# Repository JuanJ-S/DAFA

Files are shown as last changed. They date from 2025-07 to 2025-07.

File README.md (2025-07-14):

# DAFA
Dispositivo de Análisis de Fugas de Agua
# Integrantes
 - Wilson David Cortes Gonzales
 - Juan Camilo Forero Castillo
 - Andres Felipe Martinez Roa
 - Fedor Santiago Palacios Hernandez
 - Juan José Santos Pineda
 - David Valero Garzon
# Descripción
Conjunto de sensores conectados a un microcontrolador central (ESP32), que monitorean el caudal y presión del agua en puntos especificos de un sistema de tuberias. El ESP32 se conecta mediante wifi a Blynk, en donde analizan los datos dados por los sensores y se determina si estan dentro de los limites establecidos. Si los valores estan por debajo de lo permitido, se interpreta una posible fuga o conexión no registrada en el sistema, lo cual hará que el dispositivo de una alerta.
# Palabras Clave
 - Perdida de Agua
 - Internet de las Cosas
 - Sensores 
 - ESP 32
 - Gestión Hídrica
 - Sostenibilidad
# Poster
Pendiente -> ¿Como que poster :c?
# Banner de Implementación del Proyecto
En proceso. Imagen preliminar
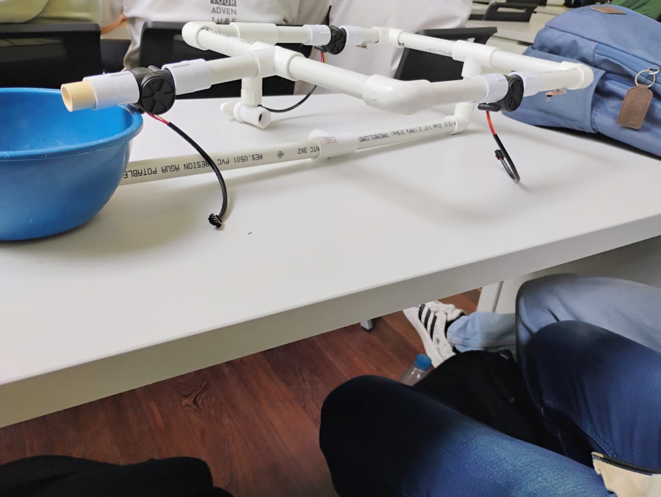
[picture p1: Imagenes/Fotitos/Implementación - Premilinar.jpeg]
Implementación Preliminar

# Video del Proyecto
Explicacion de: 
    - Problematica
    - Solución Planteada
    - Criterios para la toma de soluciones
    - Funcionamiento del proyecto para el usuario
    - Recomendaciones y Conclusiones

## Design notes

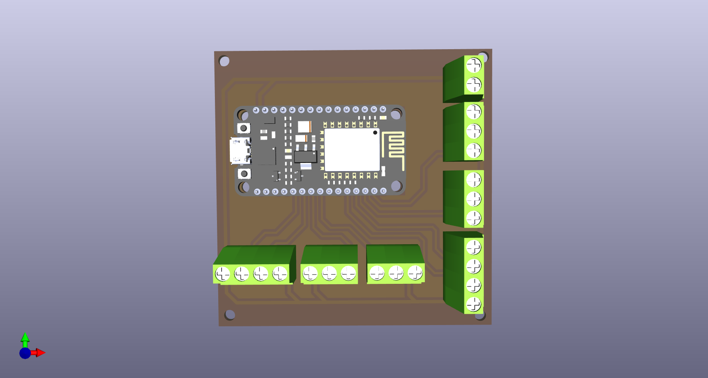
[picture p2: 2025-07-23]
Imagenes/Fotitos/Diseño 3D PCB.png

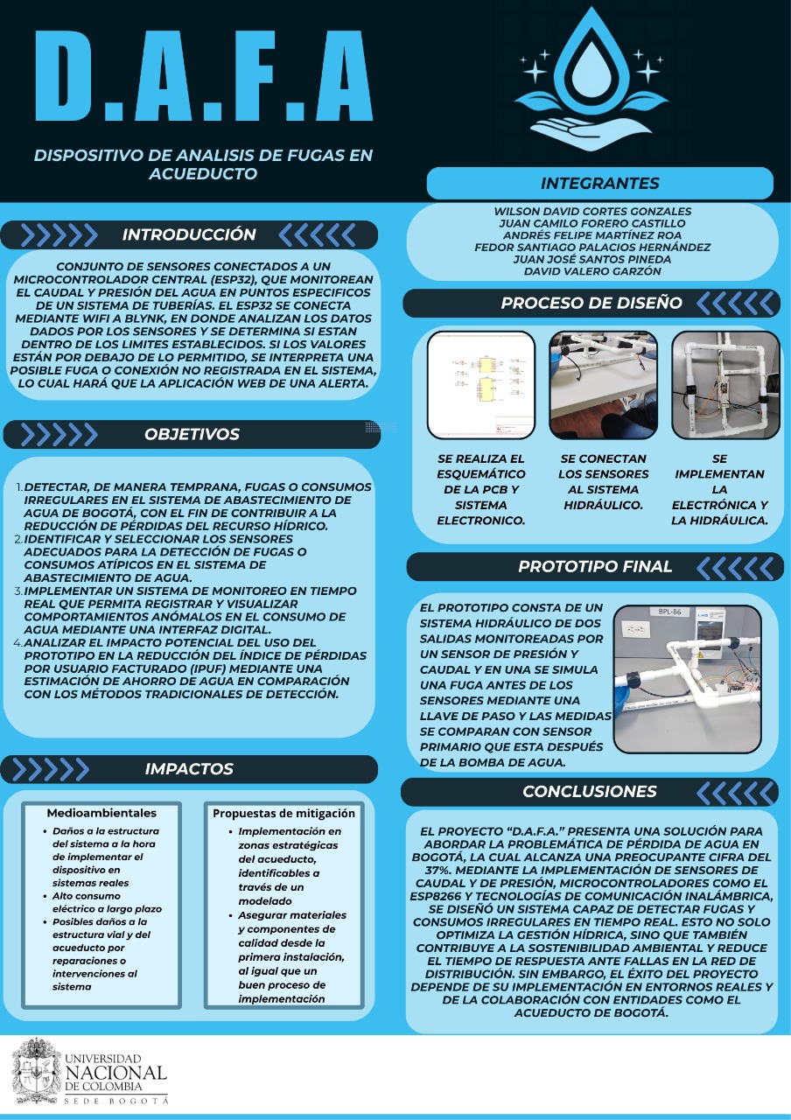
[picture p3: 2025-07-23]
Imagenes/Poster.jpeg

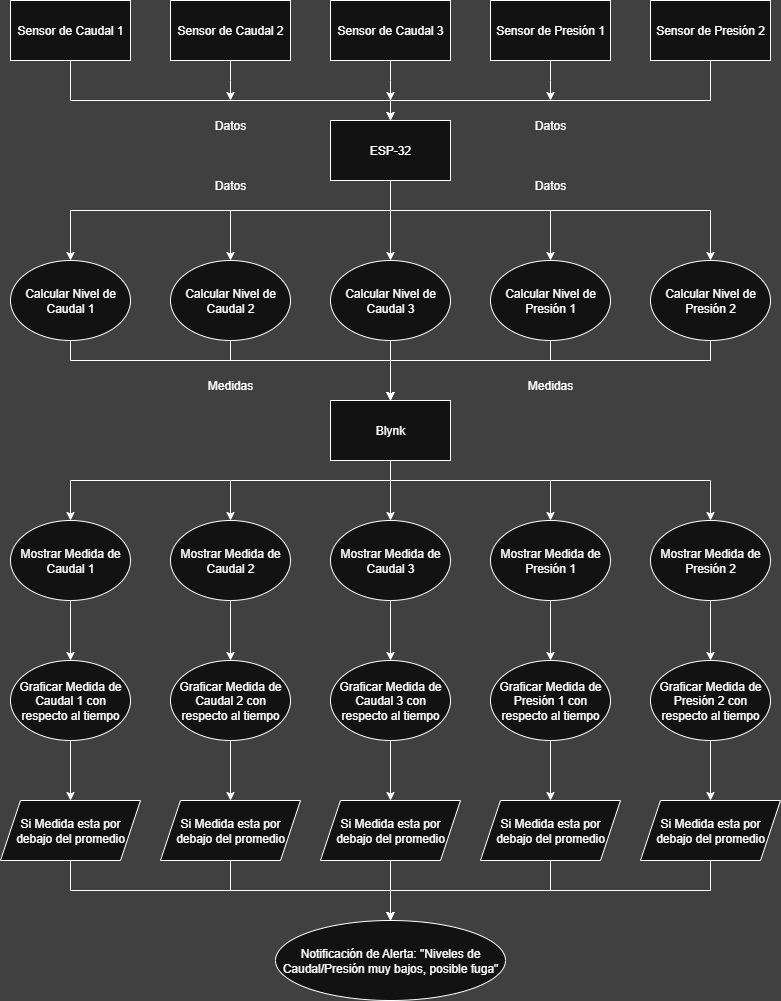
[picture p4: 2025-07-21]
Imagenes/Diagramas/Interacción con Blynk.drawio.png

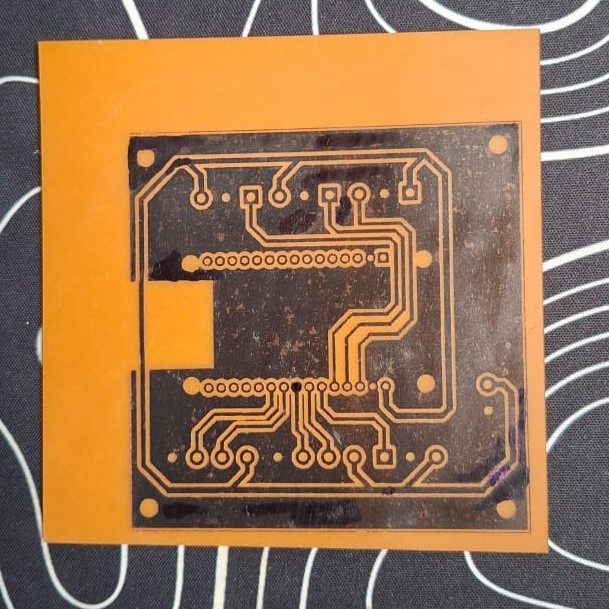
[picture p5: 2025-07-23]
Imagenes/Fotitos/Evidencias/PCB post-acido.jpeg

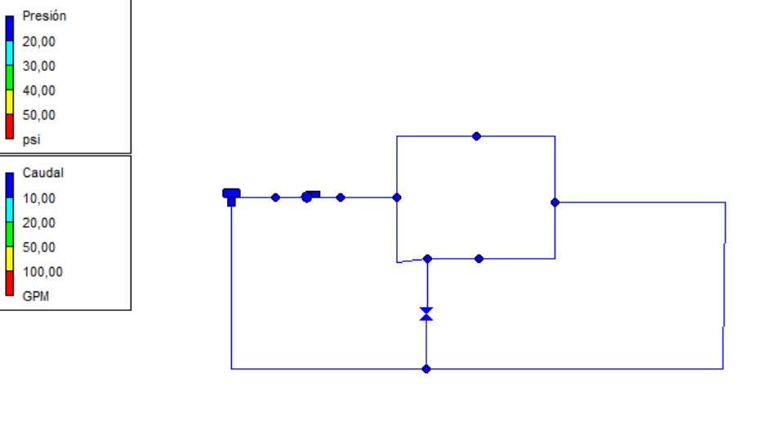
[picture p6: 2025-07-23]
Imagenes/Fotitos/Evidencias/Antigua Simulación.jpeg

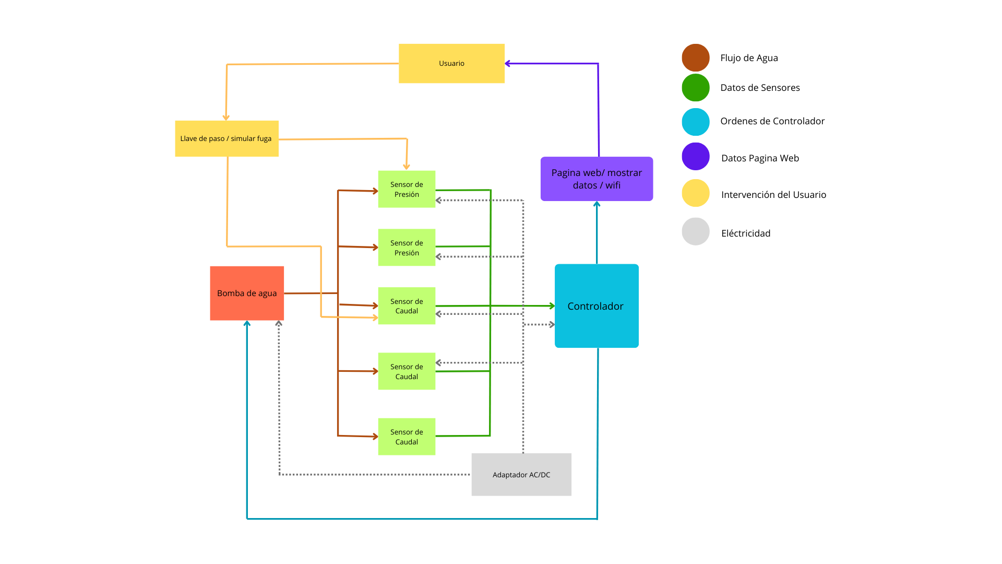
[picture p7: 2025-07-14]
Imagenes/Diagramas/Diagrama de Caja Negra.png

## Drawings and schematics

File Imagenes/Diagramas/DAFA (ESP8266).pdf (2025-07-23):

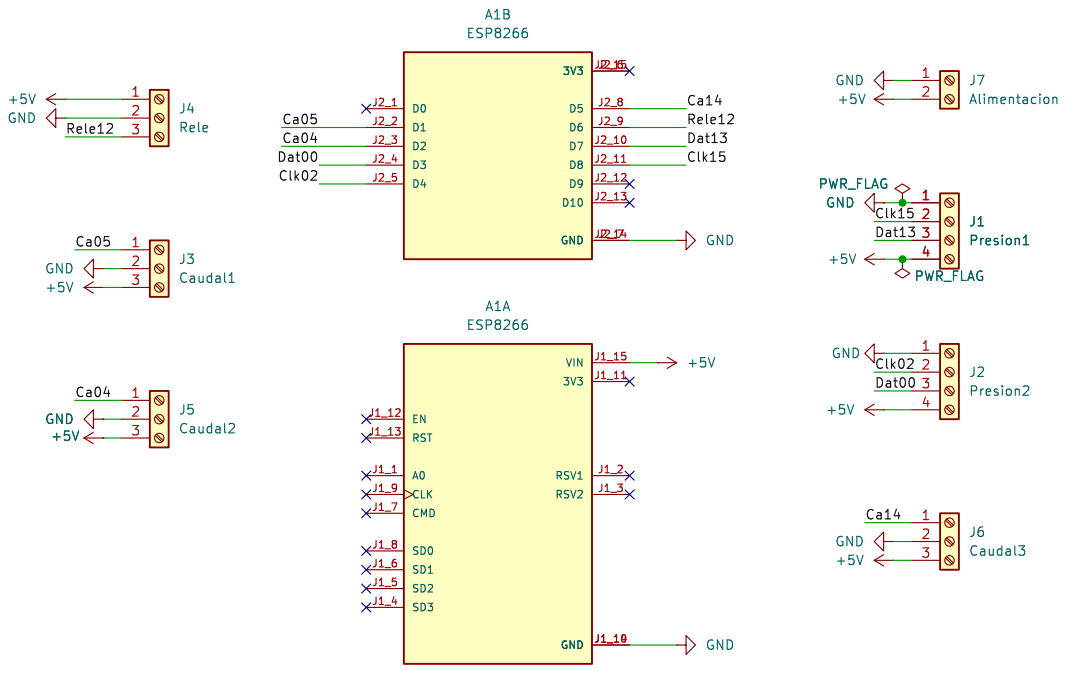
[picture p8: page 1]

Id: 1/1 Title: File: DAFA (ESP8266).kicad_sch Sheet: /

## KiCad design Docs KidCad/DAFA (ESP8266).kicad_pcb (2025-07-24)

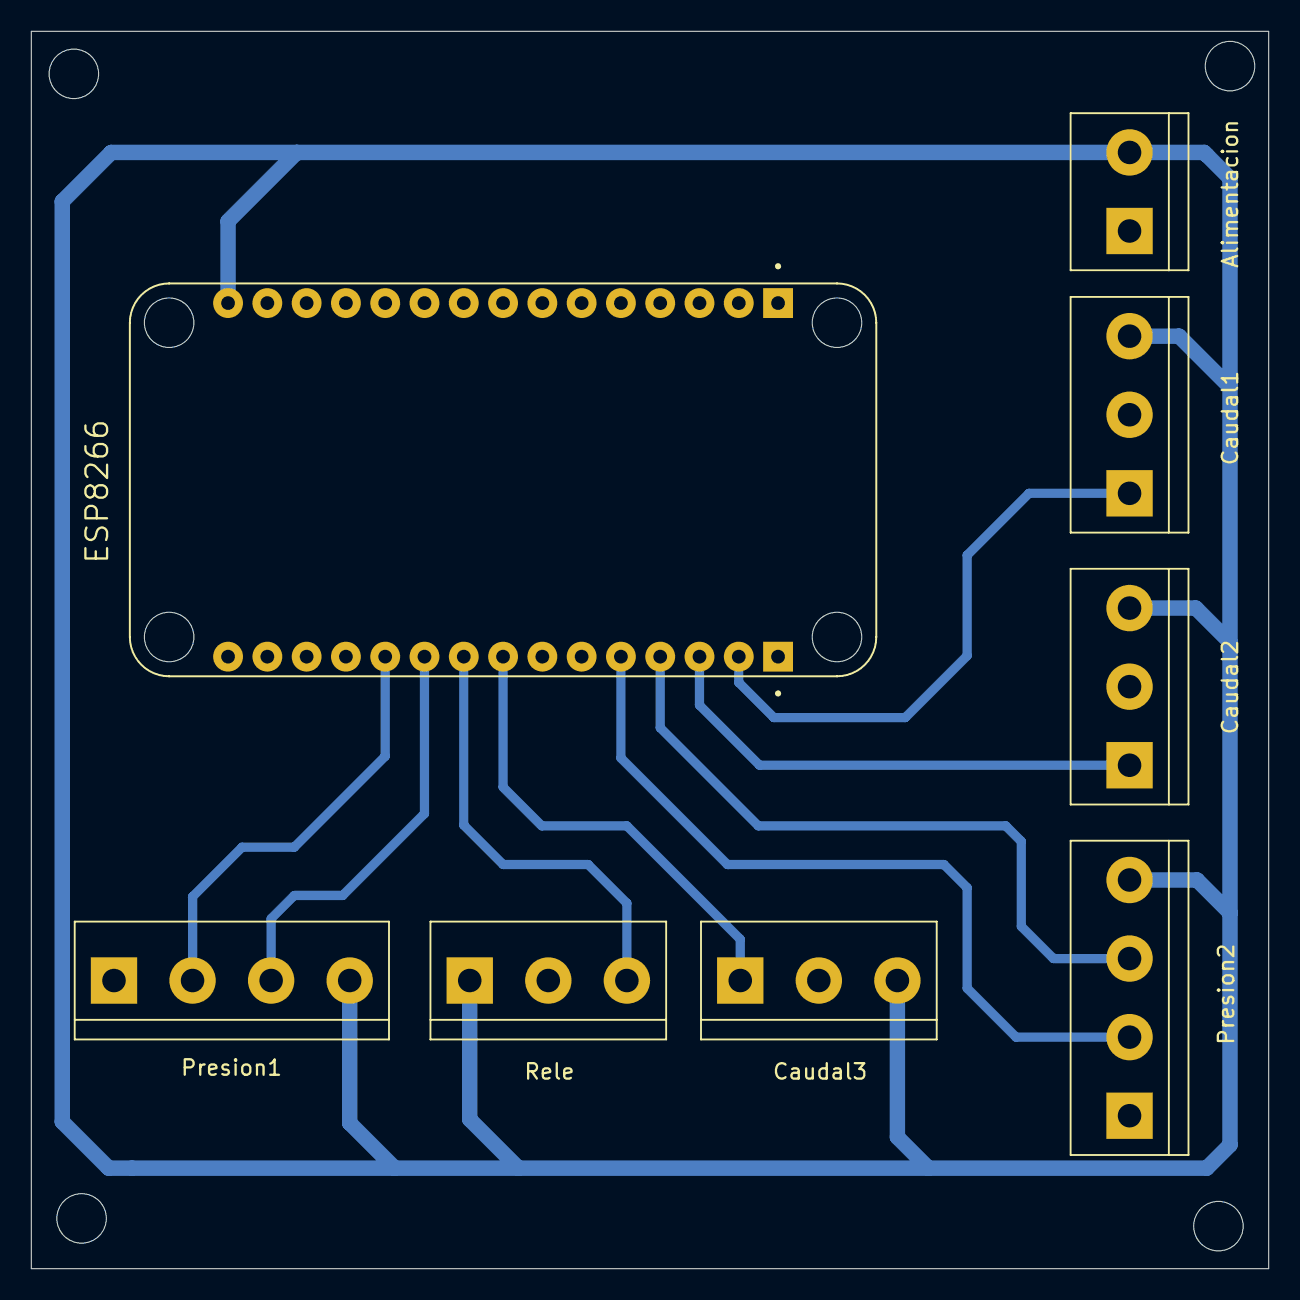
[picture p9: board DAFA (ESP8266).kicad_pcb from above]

Board: 2 copper layers, 80.0 x 80.0 mm, 8 parts (0 on the bottom side), 10 nets.

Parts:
Alimentacion: Alimentacion; TerminalBlock_bornier-2_P5.08mm
Caudal1: Caudal1; TerminalBlock_bornier-3_P5.08mm
Caudal2: Caudal2; TerminalBlock_bornier-3_P5.08mm
Caudal3: Caudal3; TerminalBlock_bornier-3_P5.08mm
ESP8266: ESP8266; SEEED_113990105
Presion1: Presion1; TerminalBlock_bornier-4_P5.08mm
Presion2: Presion2; TerminalBlock_bornier-4_P5.08mm
Rele: Rele; TerminalBlock_bornier-3_P5.08mm

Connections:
+5V: Alimentacion.2, Caudal1.3, Caudal2.3, Caudal3.3, ESP8266.J1_15 (VIN), Presion1.4, Presion2.4, Rele.1
/Ca04: Caudal2.1, ESP8266.J2_3 (D2)
/Ca05: Caudal1.1, ESP8266.J2_2 (D1)
/Ca14: Caudal3.1, ESP8266.J2_8 (D5)
/Clk02: ESP8266.J2_5 (D4), Presion2.2
/Clk15: ESP8266.J2_11 (D8), Presion1.2
/Dat00: ESP8266.J2_4 (D3), Presion2.3
/Dat13: ESP8266.J2_10 (D7), Presion1.3
/Rele12: ESP8266.J2_9 (D6), Rele.3
GND: Alimentacion.1, Caudal1.2, Caudal2.2, Caudal3.2, ESP8266.J1_10 (GND), ESP8266.J1_14 (GND), ESP8266.J2_7 (GND), ESP8266.J2_14 (GND), Presion1.1, Presion2.1, Rele.2

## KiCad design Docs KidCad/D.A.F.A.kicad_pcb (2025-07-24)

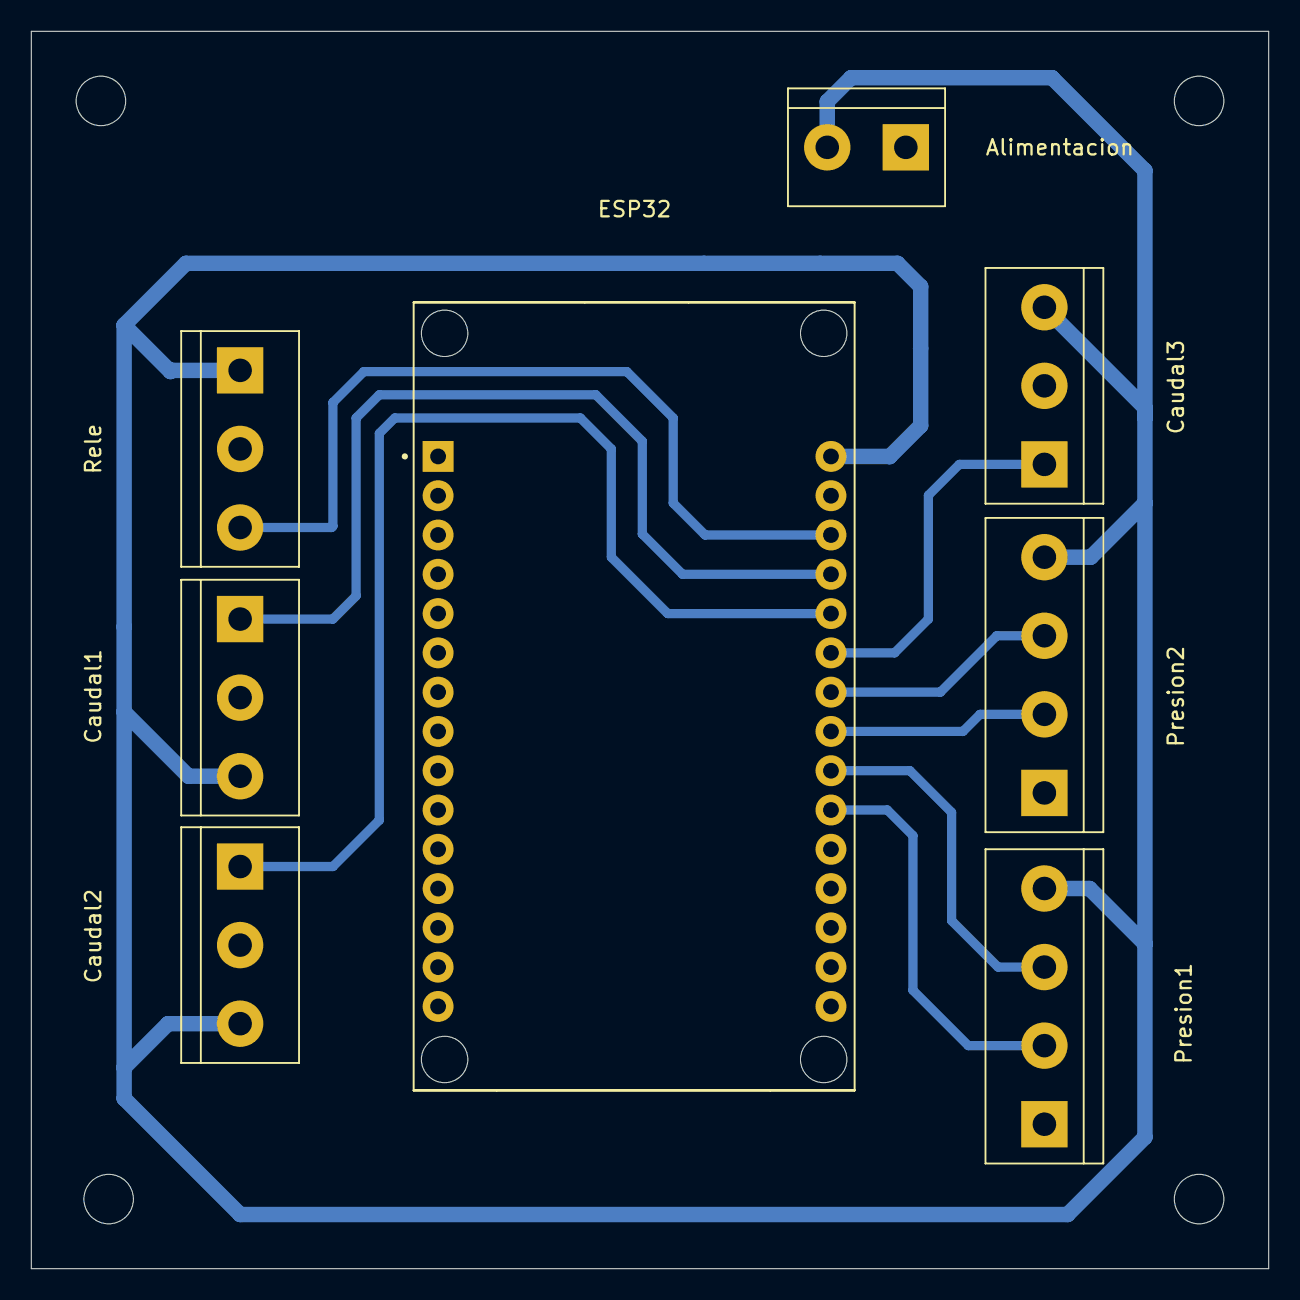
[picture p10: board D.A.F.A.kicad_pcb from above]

Board: 2 copper layers, 80.0 x 80.0 mm, 8 parts (0 on the bottom side), 10 nets.

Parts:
Alimentacion: Alimentacion; TerminalBlock_bornier-2_P5.08mm
Caudal1: Caudal1; TerminalBlock_bornier-3_P5.08mm
Caudal2: Caudal2; TerminalBlock_bornier-3_P5.08mm
Caudal3: Caudal3; TerminalBlock_bornier-3_P5.08mm
ESP32: ESP32-DEVKIT-V1; MODULE_ESP32_DEVKIT_V1
Presion1: Presion1; TerminalBlock_bornier-4_P5.08mm
Presion2: Presion2; TerminalBlock_bornier-4_P5.08mm
Rele: Rele; TerminalBlock_bornier-3_P5.08mm

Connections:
+5V: Alimentacion.2, Caudal1.3, Caudal2.3, Caudal3.3, ESP32.30 (VIN), Presion1.4, Presion2.4, Rele.1
/Ca12: Caudal1.1, ESP32.27 (D12)
/Ca14: Caudal2.1, ESP32.26 (D14)
/Ca27: Caudal3.1, ESP32.25 (D27)
/Clk25: ESP32.23 (D25), Presion2.2
/Clk32: ESP32.21 (D32), Presion1.2
/Dat26: ESP32.24 (D26), Presion2.3
/Dat33: ESP32.22 (D33), Presion1.3
/Rele13: ESP32.28 (D13), Rele.3
GND: Alimentacion.1, Caudal1.2, Caudal2.2, Caudal3.2, ESP32.2 (GND), ESP32.29 (GND), Presion1.1, Presion2.1, Rele.2

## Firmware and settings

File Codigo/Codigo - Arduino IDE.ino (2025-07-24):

//Variables de blynk
#define BLYNK_TEMPLATE_ID "TMPL2hTkAHlpS"
#define BLYNK_TEMPLATE_NAME "Quickstart Template"
#define BLYNK_AUTH_TOKEN "sauoRlbpT7XZwRfP80DVDuPRCn39Podm"

//Librerias
#include <ESP8266WiFi.h>
#include <BlynkSimpleEsp8266.h>
#include "HX710B.h"

// WiFi
char ssid[] = "Redmi Note 11";
char pass[] = "1234567890";

// Pines sensores de caudal
const byte flowPin1 = 15;   // D5 - GPIO5
const byte flowPin2 = 2;   // D4 - GPIO4
const byte flowPin3 = 4;  // D4 - GPIO14

// Pines sensores de presión
#define PRES1_DATA  5  // D7 - GPIO13
#define PRES1_CLK   18   // D4 - GPIO2
#define PRES2_DATA  19   // D3 - GPIO0
#define PRES2_CLK   21  // D8 - GPIO15

HX710B presion1(PRES1_DATA, PRES1_CLK);
HX710B presion2(PRES2_DATA, PRES2_CLK);

// Bomba
const byte bombaPin = 23; // D6 - GPIO12
bool bombaEstado = false;

// Contadores de pulsos
volatile int pulses1 = 0, pulses2 = 0, pulses3 = 0;

BlynkTimer timer;

ICACHE_RAM_ATTR void contarPulsos1() { pulses1++; }
ICACHE_RAM_ATTR void contarPulsos2() { pulses2++; }
ICACHE_RAM_ATTR void contarPulsos3() { pulses3++; }

float calcularCaudal(int pulses) {
  return (pulses * 6.0) / 450.0; // L/min
}

float calcularPresion(float voltaje) {
  return (voltaje - 0.5) * (40.0 / 4.0); // en kPa
}

void enviarDatos() {
  float c1 = calcularCaudal(pulses1);
  float c2 = calcularCaudal(pulses2);
  float c3 = calcularCaudal(pulses3);
  pulses1 = pulses2 = pulses3 = 0;

  uint32_t raw1, raw2;
  float pres1kPa = NAN, pres2kPa = NAN;

  if (presion1.read(&raw1, 1000UL) == HX710B_OK) {
    float v1 = raw1 * 5.0 / 16777215.0;
    pres1kPa = calcularPresion(v1);
  }

  if (presion2.read(&raw2, 1000UL) == HX710B_OK) {
    float v2 = raw2 * 5.0 / 16777215.0;
    pres2kPa = calcularPresion(v2);
  }

  Blynk.virtualWrite(V0, c1);
  Blynk.virtualWrite(V1, c2);
  Blynk.virtualWrite(V2, c3);
  Blynk.virtualWrite(V4, pres1kPa);
  Blynk.virtualWrite(V5, pres2kPa);
}

BLYNK_WRITE(V3) {
  bombaEstado = param.asInt();
  digitalWrite(bombaPin, bombaEstado ? HIGH : LOW);
}

void setup() {
  Serial.begin(9600);

  pinMode(flowPin1, INPUT_PULLUP);
  pinMode(flowPin2, INPUT_PULLUP);
  pinMode(flowPin3, INPUT_PULLUP);
  pinMode(bombaPin, OUTPUT);
  digitalWrite(bombaPin, LOW);

  attachInterrupt(digitalPinToInterrupt(flowPin1), contarPulsos1, RISING);
  attachInterrupt(digitalPinToInterrupt(flowPin2), contarPulsos2, RISING);
  attachInterrupt(digitalPinToInterrupt(flowPin3), contarPulsos3, RISING);

  if (!presion1.init() || !presion2.init()) {
    Serial.println("Error iniciando sensores HX710B");
  }

  Blynk.begin(BLYNK_AUTH_TOKEN, ssid, pass);
  timer.setInterval(1000L, enviarDatos);
}

void loop() {
  Blynk.run();
  timer.run();
}

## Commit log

2025-07-14 Ampliación Primera Pagina(?
    Agregue los nombres de los integrantes, de paso experimento como funciona toda esta vaina
2025-07-14 Corrección subida de imagen
    Aprendiendo a añadir imagenes
2025-07-14 Anadir Diagrama de Caja Negra
    Eso mismo
2025-07-16 Create Bocetado, Sistema de Tuberias.jpeg
2025-07-16 Create Diagrama de Flujo del Programa.png
2025-07-23 Create Esquema ESP32.jpeg
2025-07-23 Imágenes Diseño Case
2025-07-23 Ajuste de poster
2025-07-23 Proceso PCB
2025-07-24 Create Codigo - Arduino IDE.ino
2025-07-24 Documentos del diseño de la pcb en kitcad
    [D.A.F.A.kicad_pcb, D.A.F.A.kicad_sch, DAFA (ESP8266).kicad_pcb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]
